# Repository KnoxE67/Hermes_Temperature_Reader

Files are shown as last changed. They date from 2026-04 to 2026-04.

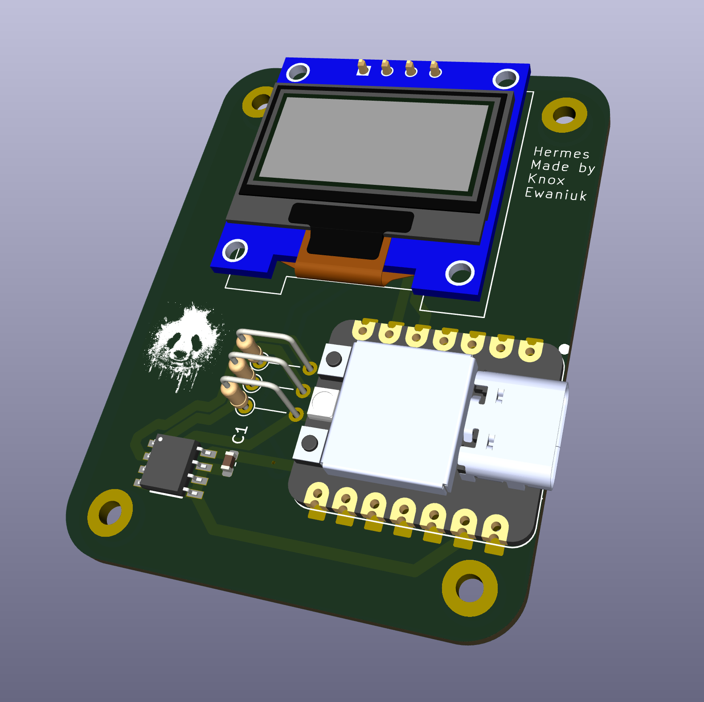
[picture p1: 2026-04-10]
Images/3D Viewer.png

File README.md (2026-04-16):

# Hermes_Temperature_Reader
Building a Custom Hermes project with a LM75AD_118, XIAO RP2040, and a 0.96” 128 X 64 OLED DISPLAY

# What?

So this project is about making something clean, cool, and something Im going to use for a long time.
It uses a PCB, a XIAO RP2040, a SSD1306 OLED Display, a LM75AD,118 Temperature sensor, 
One 0.1 µF Ceramic Capacitor, Two 4.7k ohm Resistors, and One 10k ohm Resistor.

# Why?

So I did the project so that I could learn how to build something using a Datasheet which I havn't done without help before,
cool, nice, and something I would actual use unlike the Blueprint Projects: Custom Hackpad and RP2040 DevBoard.
I also did this project because I was bored and waiting for my other project Pathfinder to get reviewed and approved.

# Pictures

3D Model:

3D Viewer

PCB:

PCB Viewer

Schematic: 

Schematic

# BOM

| Name | Purpose | Quantity | Total Cost (USD) | Link | Distributor |
|---|---|---|---|---|---|
| PCB | To connect everything together | 5 | 5.31 | | JLCPCB |
| 10 kOhms ±5% 0.25W, 1/4W Through Hole Resistor Axial Carbon Film | Used to dampen the Temperature Sensors data, again got 9 extra because it was cheaper | 10 | 0.31 | https://www.digikey.com/en/products/detail/stackpole-electronics-inc/CF14JT10K0/1741265 | Digikey |
| 4.7 kOhms ±5% 0.5W, 1/2W Through Hole Resistor Axial Carbon Film | To pull up the SDA and SCL, got 8 extra becausae it was cheaper | 10 | 0.43 | https://www.digikey.com/en/products/detail/stackpole-electronics-inc/CF12JT4K70/1741152 | Digikey |
| 0.1 µF ±10% 25V Ceramic Capacitor X7R 0603 (1608 Metric) | It's a Cermanic Capacitor for the Temperature Sensor. Got some extra because again I'm going to manually solder these by hand. | 10 | 0.52 | https://www.digikey.com/en/products/detail/kemet/C0603C104K3RACTU/416044 | Digikey |
| LM75AD,118 Temperature Sensor Digital, Local -55°C ~ 125°C 11 b 8-SO | To get the temperature where ever it is powered, also got 1 extra because I'm going to be soldering this manually and not through JLCPCB. | 2 | 1.42 | https://www.digikey.com/en/products/detail/nxp-usa-inc/LM75AD-118/1692795 | Digikey |
| RP2040 XIAO RP2040 - ARM® Cortex®-M0+ MCU 32-Bit Embedded Evaluation Board | This is used to power the board | 1 | 5.15 | https://www.digikey.com/en/products/detail/seeed-technology-co-ltd/102010428/14672129 | Digikey |

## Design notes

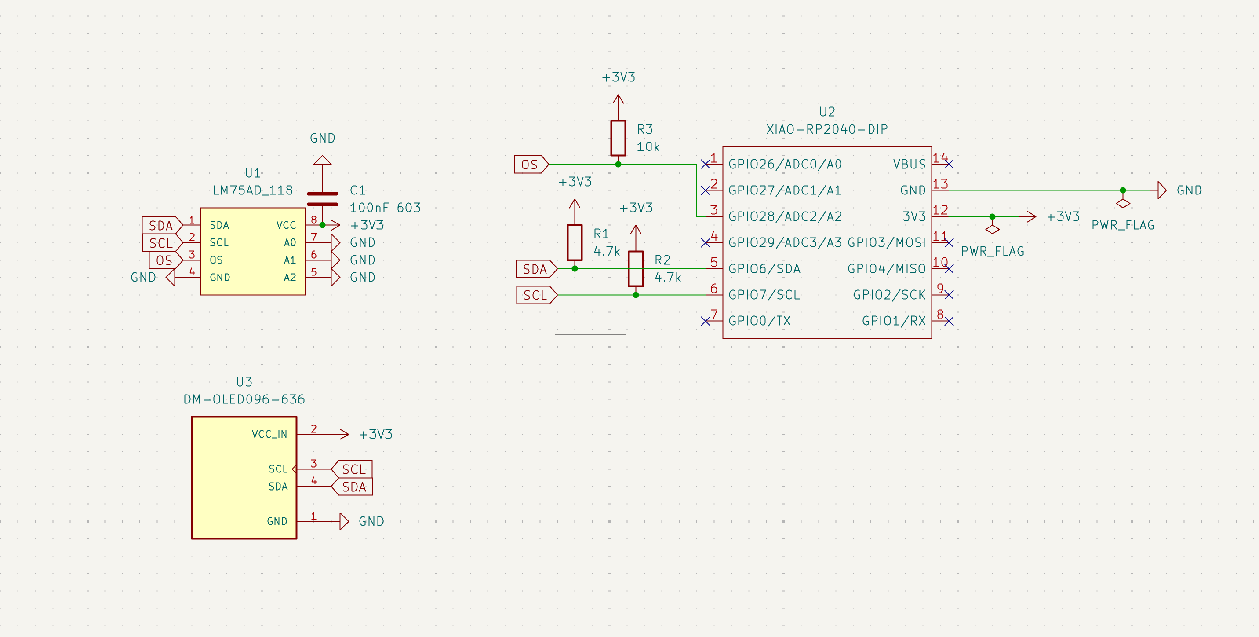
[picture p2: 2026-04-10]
Images/Schematic.png

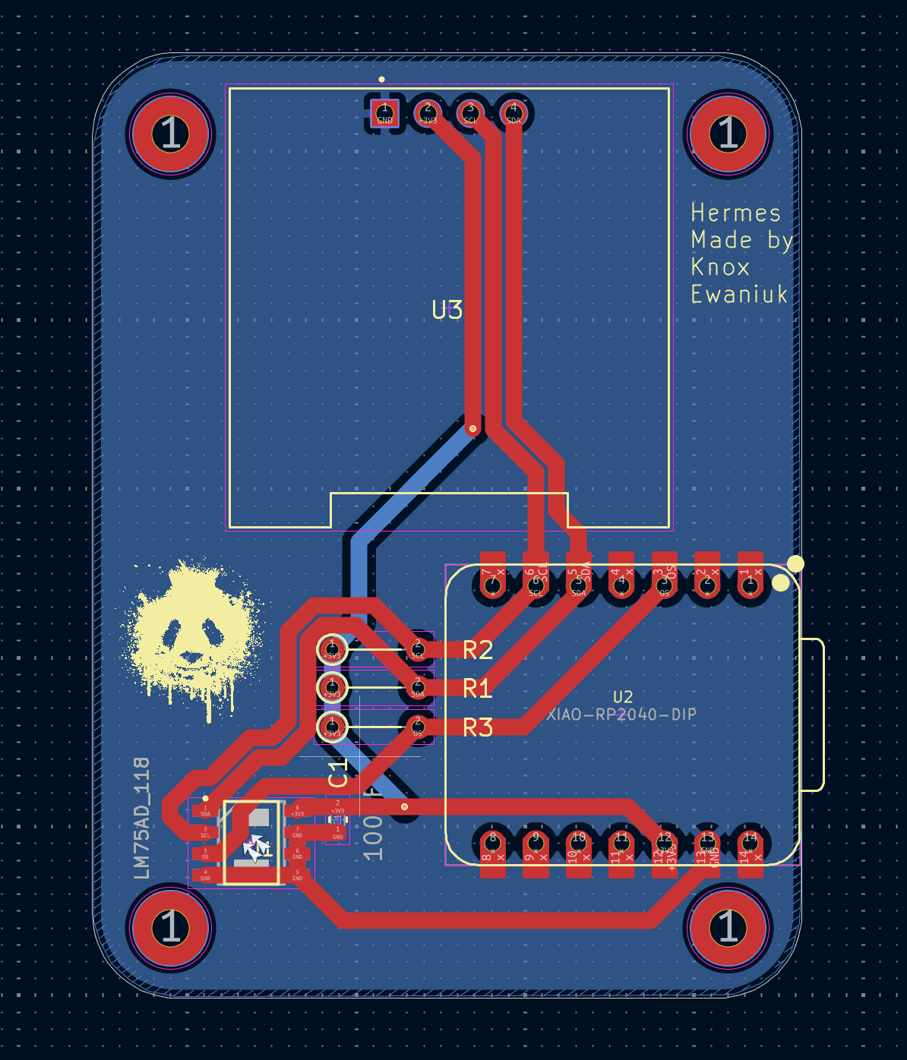
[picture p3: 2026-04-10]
Images/PCB Viewer.png

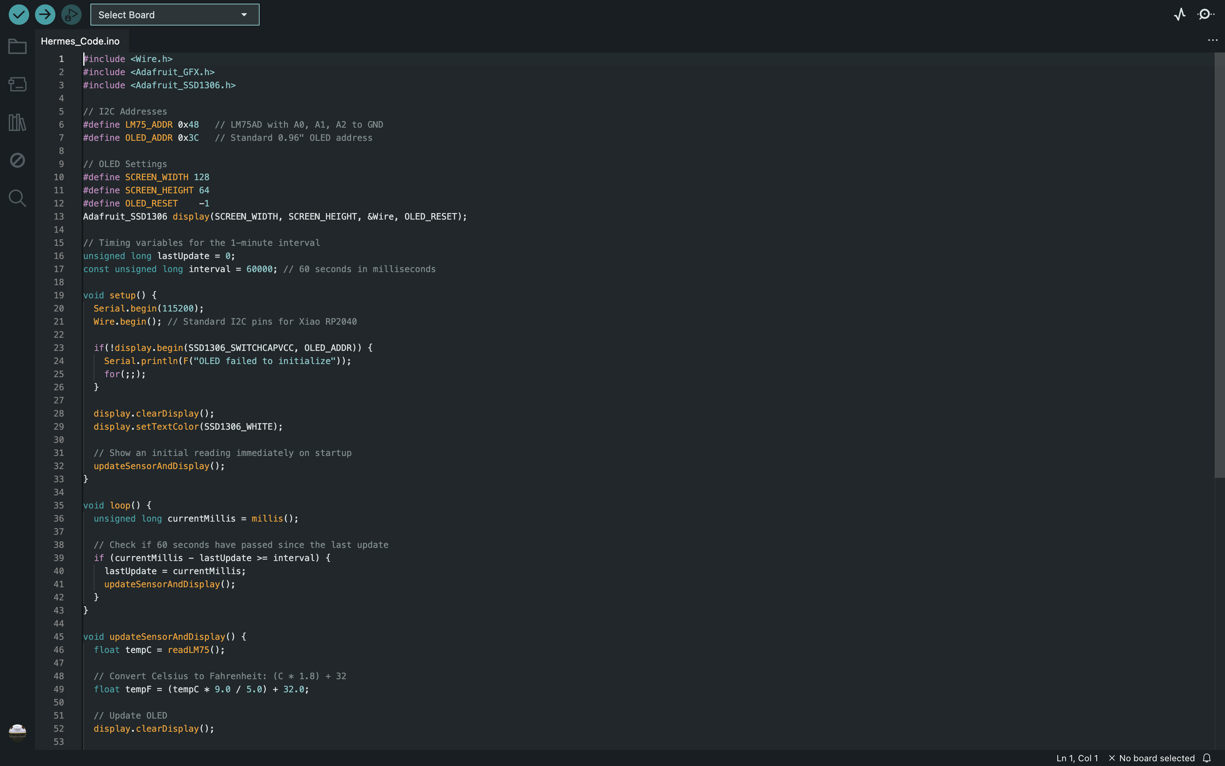
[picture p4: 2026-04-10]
Images/TOP.png

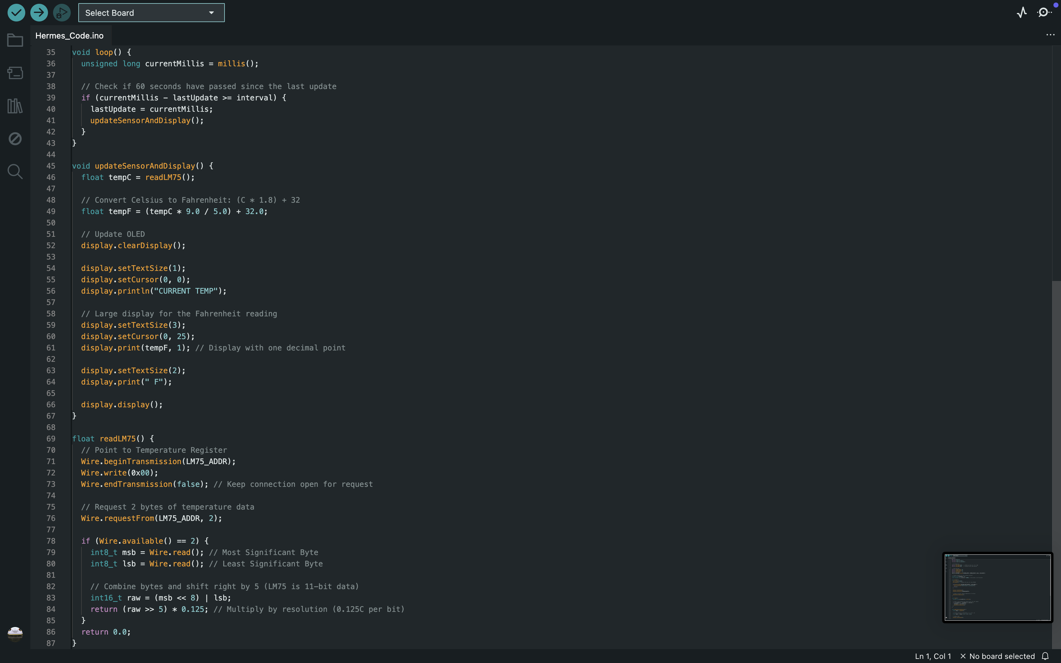
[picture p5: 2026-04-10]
Images/BOTTOM.png

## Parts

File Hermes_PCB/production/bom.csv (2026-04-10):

Designator | Footprint | Quantity | Value | LCSC Part #
C1 | 0603 | 1 | 100nF
R1, R2 | R_Axial_DIN0204_L3.6mm_D1.6mm_P5.08mm_Vertical | 2 | 4.7k
R3 | R_Axial_DIN0204_L3.6mm_D1.6mm_P5.08mm_Vertical | 1 | 10k
U1 | LM75AD_118 | 1 | LM75AD_118 | LM75AD,118
U2 | XIAO-RP2040-DIP | 1 | XIAO-RP2040-DIP
U3 | MODULE_DM-OLED096-636 | 1 | DM-OLED096-636

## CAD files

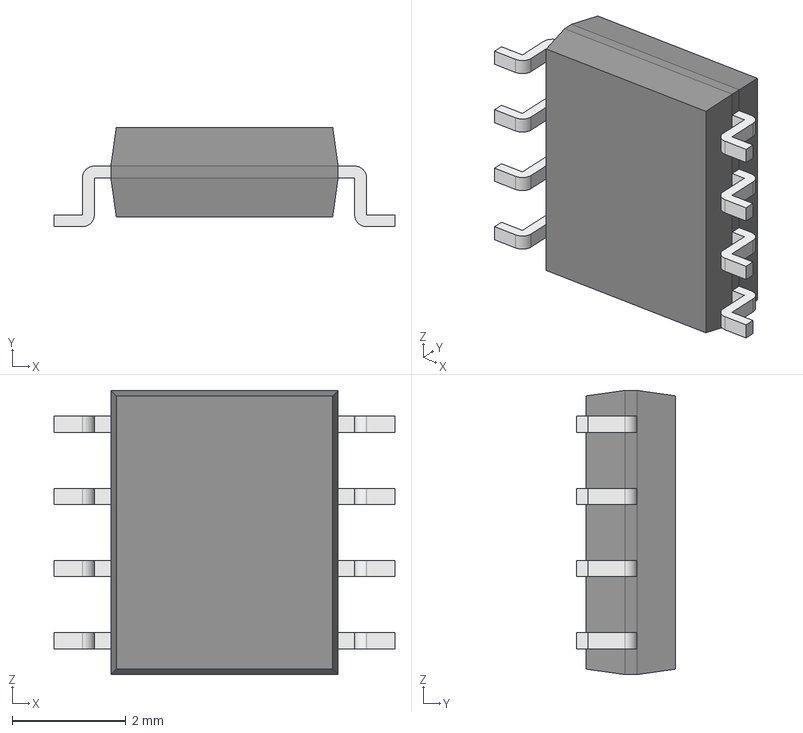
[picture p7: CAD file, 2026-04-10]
Hermes_PCB/Files/LM75AD_118.step
6.00 x 1.75 x 5.00 mm
Body001 (Mirror #1) x 4
XY-plane x 12
X-axis x 12

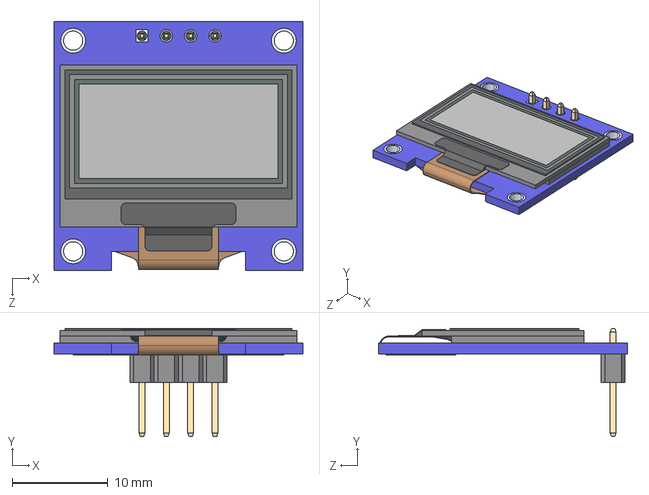
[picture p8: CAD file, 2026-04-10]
Hermes_PCB/Files/DM-OLED096-636.step
26.0 x 11.3 x 26.0 mm
DM-OLED096-636_Module
DM-OLED096-636_Panel

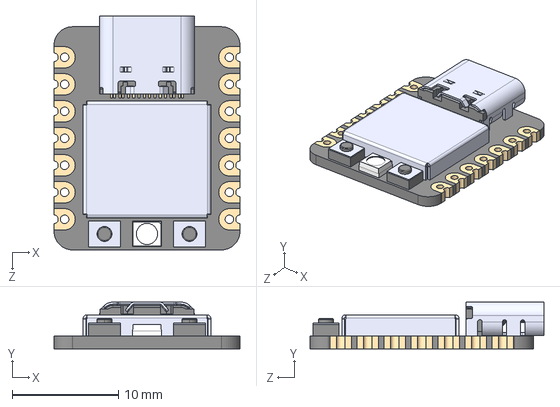
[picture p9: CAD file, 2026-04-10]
Hermes_PCB/Files/102010428.STEP
17.5 x 4.40 x 22.0 mm

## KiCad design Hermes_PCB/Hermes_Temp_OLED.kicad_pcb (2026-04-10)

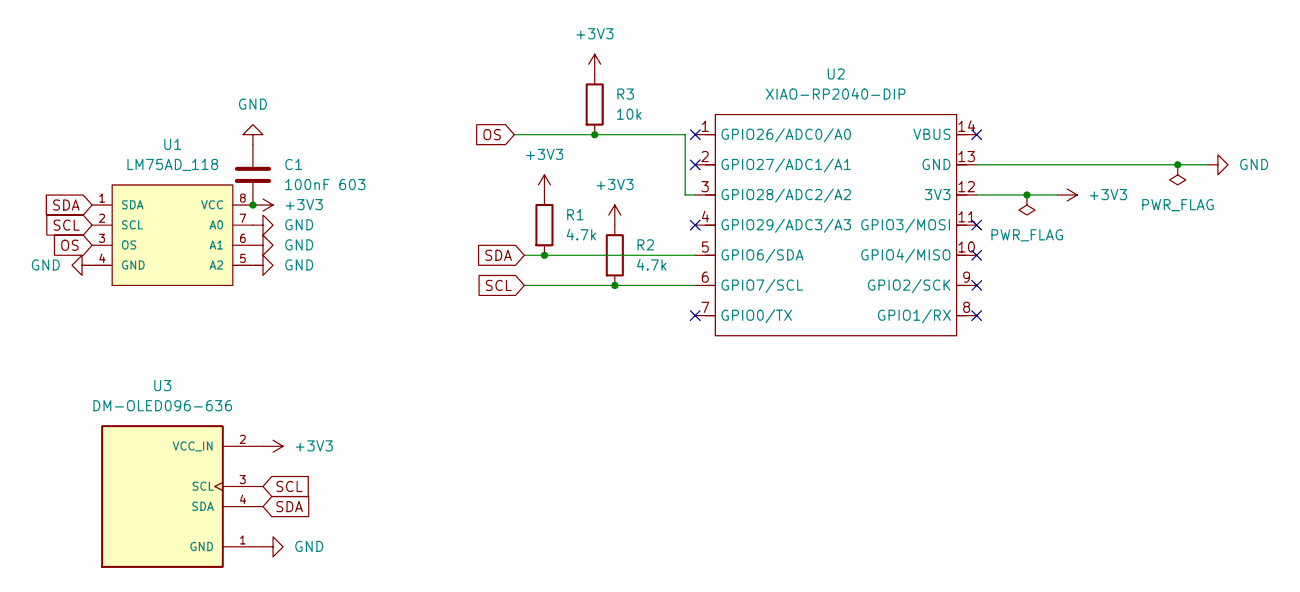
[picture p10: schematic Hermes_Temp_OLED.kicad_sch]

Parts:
C1: 100nF 603; C_0603_1608Metric
R1, R2: 4.7k; R_Axial_DIN0204_L3.6mm_D1.6mm_P5.08mm_Vertical
R3: 10k; R_Axial_DIN0204_L3.6mm_D1.6mm_P5.08mm_Vertical
U1: LM75AD_118; MPN LM75AD,118
U2: XIAO-RP2040-DIP
U3: DM-OLED096-636; MODULE_DM-OLED096-636; PARTREV 2018-09-10

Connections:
+3V3: C1.2, R1.1, R2.1, R3.1, U1.8 (VCC), U2.12 (3V3), U3.2 (VCC_IN)
GND: C1.1, U1.4 (GND), U1.5 (A2), U1.6 (A1), U1.7 (A0), U2.13 (GND), U3.1 (GND)
OS: R3.2, U1.3 (OS), U2.3 (GPIO28/ADC2/A2)
SCL: R2.2, U1.2 (SCL), U2.6 (GPIO7/SCL), U3.3 (SCL)
SDA: R1.2, U1.1 (SDA), U2.5 (GPIO6/SDA), U3.4 (SDA)

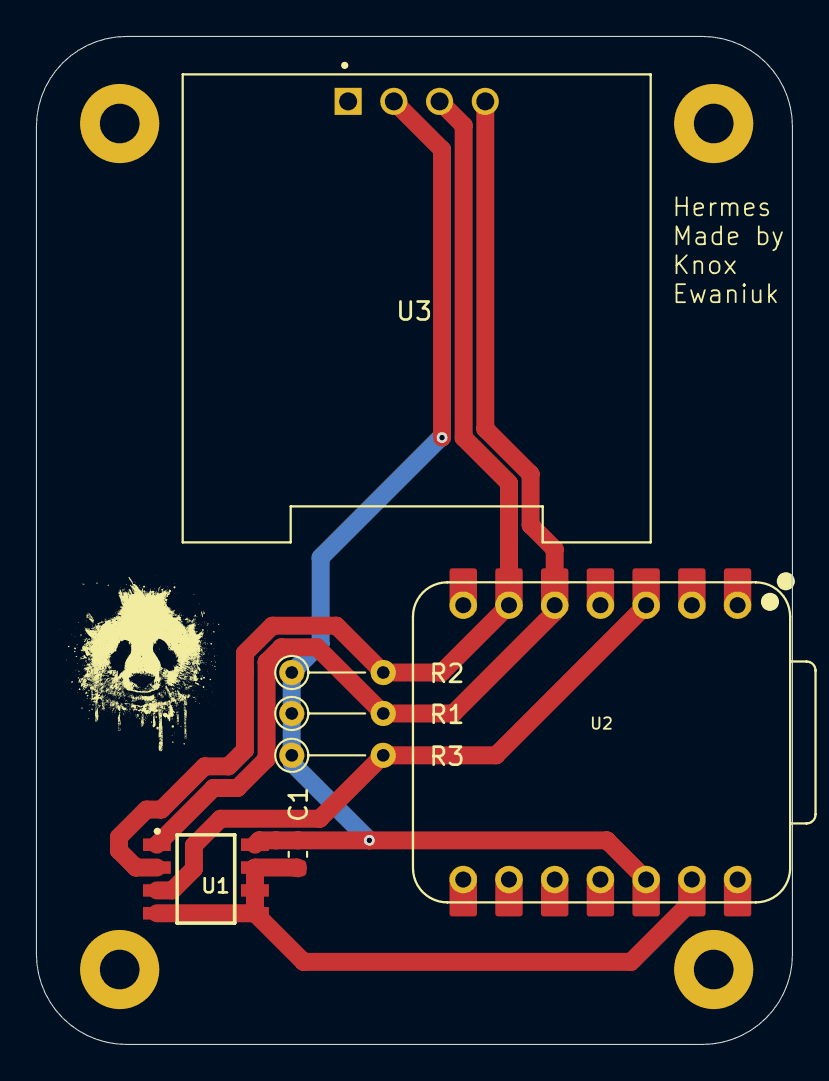
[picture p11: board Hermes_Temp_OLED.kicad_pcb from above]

Board: 2 copper layers, 42.0 x 56.0 mm, 7 parts (0 on the bottom side), 5 nets.

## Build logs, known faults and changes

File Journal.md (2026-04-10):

# Hermes_Temperature_Reader
Building a Custom Hermes project with a LM75AD_118, XIAO RP2040, and a 0.96” 128 X 64 OLED DISPLAY
# 4/9/2026 - Worked on finding a Sensor and the Schematic
Time spent: 2h

Worked on finding a Sensor and the Schematic by researching the JLCPCB catalog for a sensor that I thought would be cool, and settled on a Temperature sensor, which would be shown on an OLED display so that I could know the temperature in my room.

Here is a photo of my schematic:

Screenshot 2026-04-09 at 10.37.18 AM

Here is a photo of the ERC:

Screenshot 2026-04-09 at 10.37.43 AM

# 4/9/2026 - I worked on finishing the schematic, and pcb layout
Time spent: 3h

I worked on finishing the schematic and PCB layout by putting the parts in places that made the whole thing look really cool. I also rounded the corners of the PCB and added mounting holes so that I could make a case for it.

Here is a photo of the schematic: 

Screenshot 2026-04-09 at 4.22.55 PM

Here is a photo of the PCB: 

Screenshot 2026-04-09 at 4.23.56 PM

Here is a photo of the 3D Viewer:

Screenshot 2026-04-09 at 4.25.12 PM

# 4/9/2026 - Worked on Code, and final placements of parts
Time spent: 3h

Worked on the code by looking at the example code and making a rough code that will later be fixed if needed. Also, final placements of parts by getting some recommedations from some people on slack and made it so everything looks even and amazing.

Here is the photo's of the Code:

TOP

BOTTOM

Here is a photo of the PCB:

Screenshot 2026-04-09 at 7.29.17 PM

Here is a photo of the 3D Viewer:

Screenshot 2026-04-09 at 7.30.57 PM

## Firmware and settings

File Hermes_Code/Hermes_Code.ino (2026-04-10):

#include <Wire.h>
#include <Adafruit_GFX.h>
#include <Adafruit_SSD1306.h>

// I2C Addresses
#define LM75_ADDR 0x48   // LM75AD with A0, A1, A2 to GND
#define OLED_ADDR 0x3C   // Standard 0.96" OLED address

// OLED Settings
#define SCREEN_WIDTH 128 
#define SCREEN_HEIGHT 64 
#define OLED_RESET    -1 
Adafruit_SSD1306 display(SCREEN_WIDTH, SCREEN_HEIGHT, &Wire, OLED_RESET);

// Timing variables for the 1-minute interval
unsigned long lastUpdate = 0;
const unsigned long interval = 60000; // 60 seconds in milliseconds

void setup() {
  Serial.begin(115200);
  Wire.begin(); // Standard I2C pins for Xiao RP2040

  if(!display.begin(SSD1306_SWITCHCAPVCC, OLED_ADDR)) {
    Serial.println(F("OLED failed to initialize"));
    for(;;); 
  }

  display.clearDisplay();
  display.setTextColor(SSD1306_WHITE);
  
  // Show an initial reading immediately on startup
  updateSensorAndDisplay();
}

void loop() {
  unsigned long currentMillis = millis();

  // Check if 60 seconds have passed since the last update
  if (currentMillis - lastUpdate >= interval) {
    lastUpdate = currentMillis;
    updateSensorAndDisplay();
  }
}

void updateSensorAndDisplay() {
  float tempC = readLM75();
  
  // Convert Celsius to Fahrenheit: (C * 1.8) + 32
  float tempF = (tempC * 9.0 / 5.0) + 32.0;

  // Update OLED
  display.clearDisplay();
  
  display.setTextSize(1);
  display.setCursor(0, 0);
  display.println("CURRENT TEMP");

  // Large display for the Fahrenheit reading
  display.setTextSize(3); 
  display.setCursor(0, 25);
  display.print(tempF, 1); // Display with one decimal point
  
  display.setTextSize(2);
  display.print(" F");
  
  display.display();
}

float readLM75() {
  // Point to Temperature Register
  Wire.beginTransmission(LM75_ADDR);
  Wire.write(0x00); 
  Wire.endTransmission(false); // Keep connection open for request

  // Request 2 bytes of temperature data
  Wire.requestFrom(LM75_ADDR, 2);

  if (Wire.available() == 2) {
    int8_t msb = Wire.read(); // Most Significant Byte
    int8_t lsb = Wire.read(); // Least Significant Byte
    
    // Combine bytes and shift right by 5 (LM75 is 11-bit data)
    int16_t raw = (msb << 8) | lsb;
    return (raw >> 5) * 0.125; // Multiply by resolution (0.125C per bit)
  }
  return 0.0;
}
